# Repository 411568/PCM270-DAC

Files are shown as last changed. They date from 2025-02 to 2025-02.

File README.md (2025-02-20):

<p align="center">
PCM270-DAC
</p>

<h2>🧐 Features</h2>

USB DAC based on the PCM270xC iC. Powered by a USB type C connector. Output is compliant with the Line Out specification.
The included gerber files and BOM are made for JLCPCB. All of the components are taken from the LCSC library, meaning you can have the board assembled by JLC.
Important note: the board has not been tested yet.

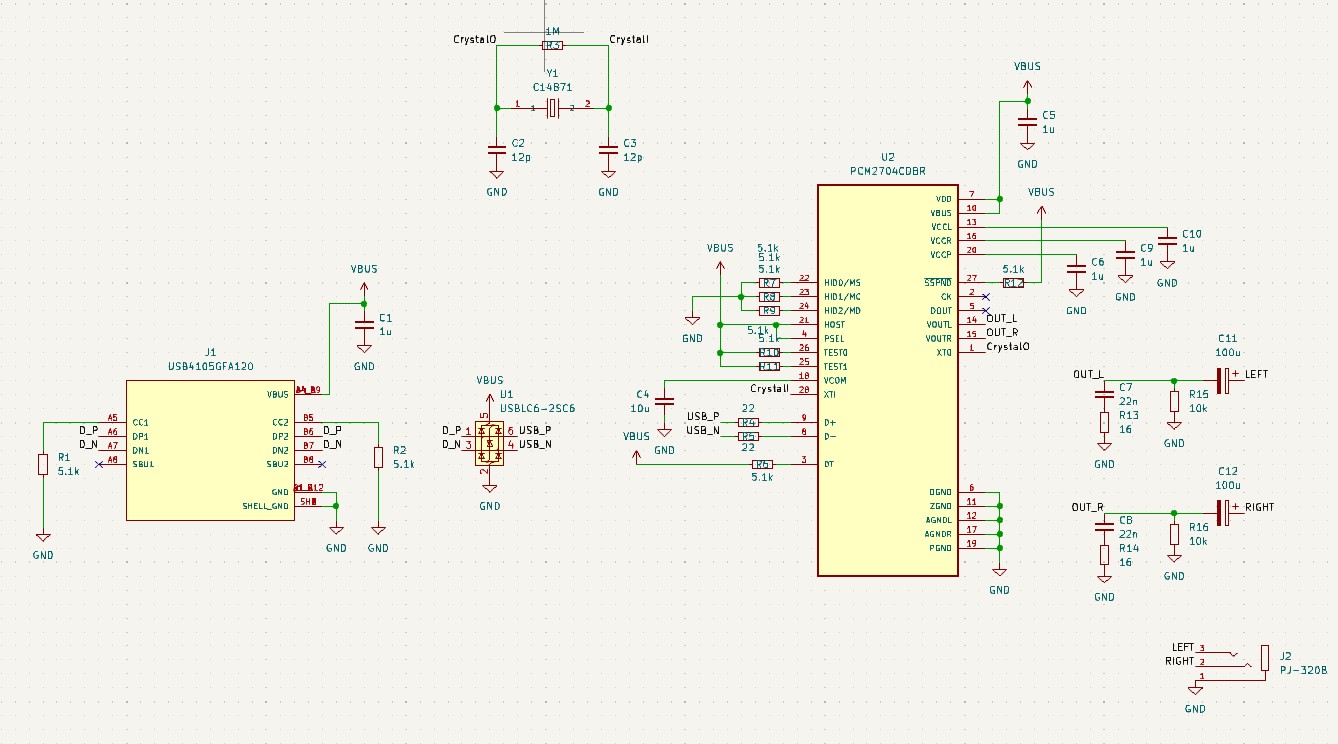
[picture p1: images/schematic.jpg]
schematic


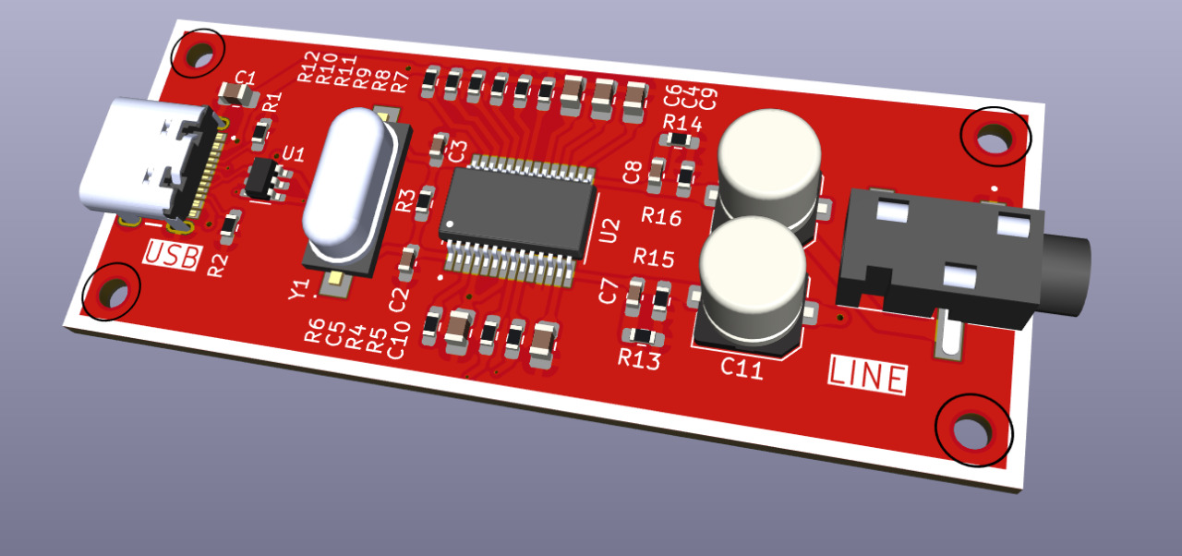
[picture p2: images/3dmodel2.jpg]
PCB 3d model


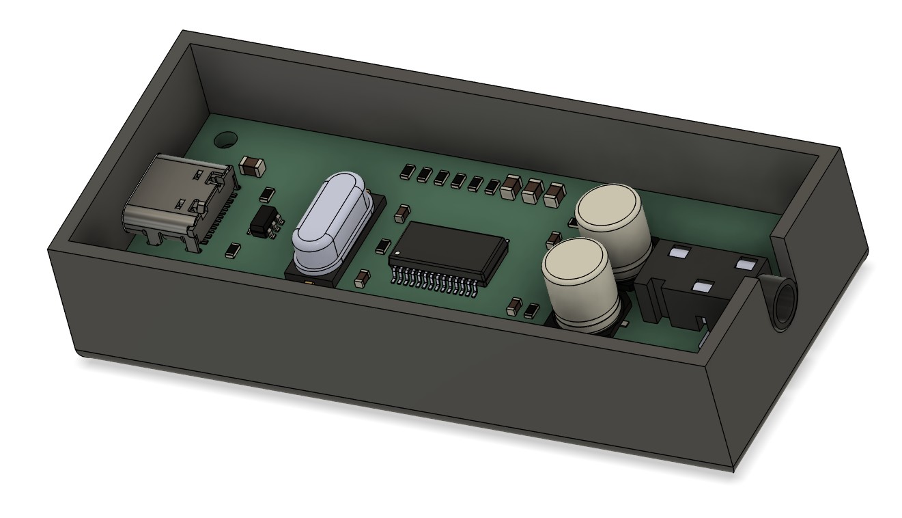
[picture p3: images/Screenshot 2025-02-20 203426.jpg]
enclosure


<h2>🛡️ License:</h2>

This project is licensed under the MIT License.

<h2> 🙋‍♂️Authors </h2>

- Krzysztof Sikora

<h2>💖Like my work?</h2>

If you have any questions about the project feel free to contact us via email: krzysieksikora717@gmail.com

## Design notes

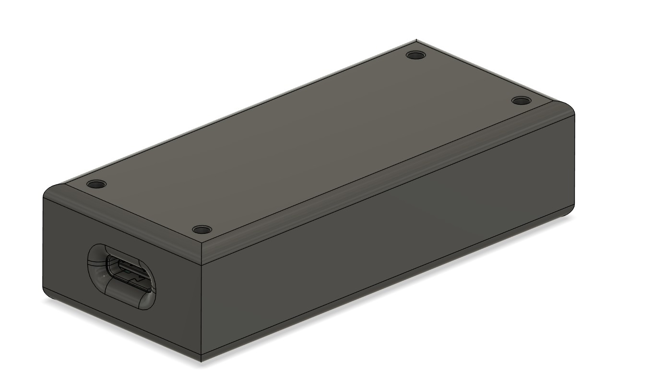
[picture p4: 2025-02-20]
images/Screenshot 2025-02-20 203409.jpg

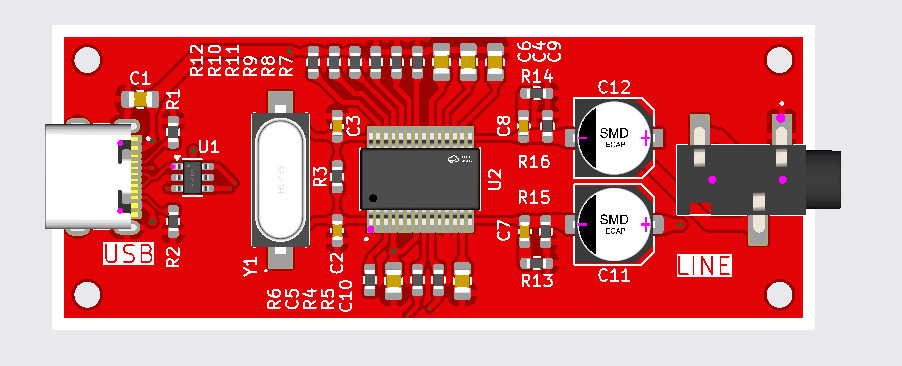
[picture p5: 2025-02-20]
images/3dmodel.jpg

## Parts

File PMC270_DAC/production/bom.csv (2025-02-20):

Designator | Footprint | Quantity | Value | LCSC Part #
C1, C10, C5, C6, C9 | 0805 | 5 | 1u | C28323
C11, C12 | C_Elec_6.3x7.7 | 2 | 100u | C3338
C2, C3 | 0603 | 2 | 12p | C38523
C4 | 0805 | 1 | 10u | C15850
C7, C8 | 0603 | 2 | 22n | C21122
LINE | BOOMELE_PJ-320B | 1 | PJ-320B | C18594
R1, R10, R11, R12, R2, R6, R7, R8, R9 | 0603 | 9 | 5.1k | C23186
R13, R14 | 0603 | 2 | 16 | C23345
R15, R16 | 0603 | 2 | 10k | C15401
R3 | 0603 | 1 | 1M | C22935
R4, R5 | 0603 | 2 | 22 | C23345
U1 | SOT-23-6 | 1 | USBLC6-2SC6 | C7519
U2 | SOP65P780X200-28N | 1 | PCM2704CDBR | C2859784
USB | GCT_USB4105GFA120 | 1 | USB4105GFA120 | C136423
Y1 | XTAL1170X500X450 | 1 | C14871 | C14871

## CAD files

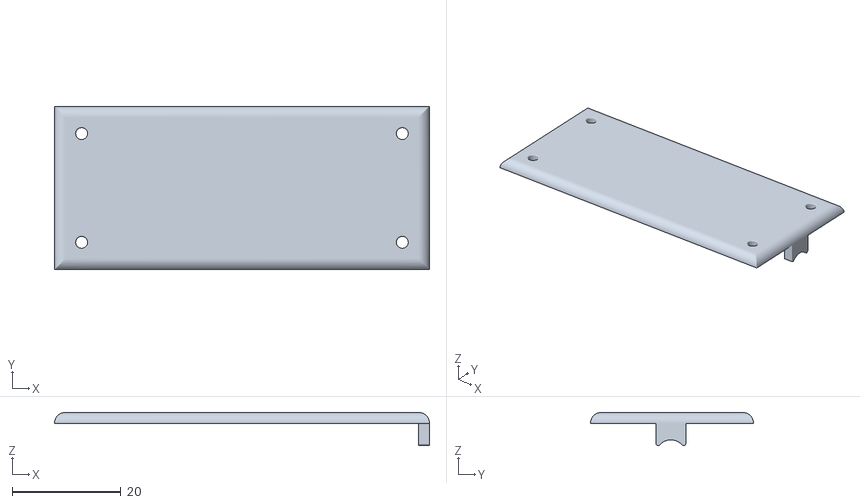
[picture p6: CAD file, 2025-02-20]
3D models/PMC270_DAC top.stl
69.0 x 30.0 x 6.10

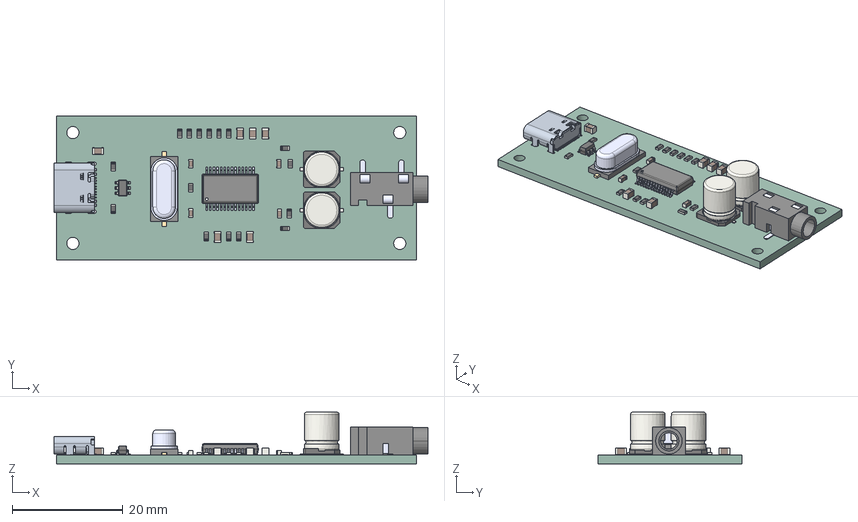
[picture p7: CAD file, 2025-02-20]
PMC270_DAC/PMC270_DAC.step
67.5 x 26.0 x 9.35 mm
R_0603_1608Metric x 16
C_0805_2012Metric x 6
C_Elec_63x77 x 2
C_0603_1608Metric x 4
SN65C3243DBR
SOT_23_6
FOXSDLF_160-20
PJ-320B
USB4105GFA120
PMC270_DAC_PCB

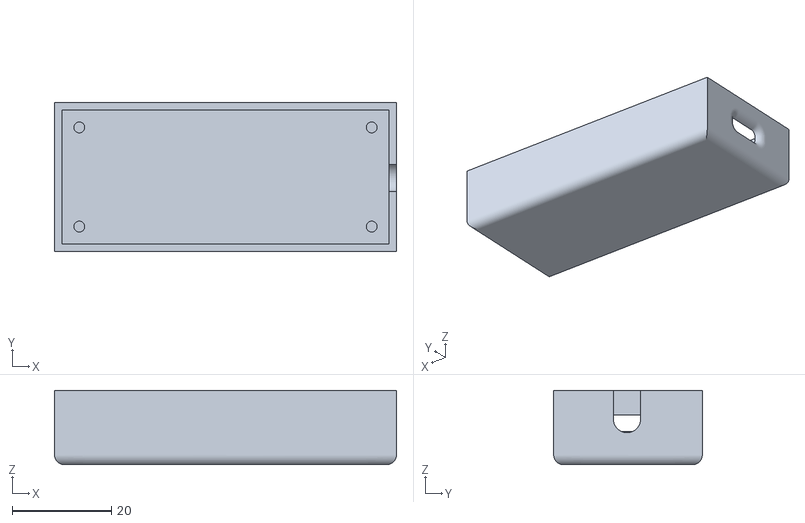
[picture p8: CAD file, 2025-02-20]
3D models/PMC270_DAC bottom.stl
69.0 x 30.0 x 15.0

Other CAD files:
3D models/PMC270_DAC v2.f3d

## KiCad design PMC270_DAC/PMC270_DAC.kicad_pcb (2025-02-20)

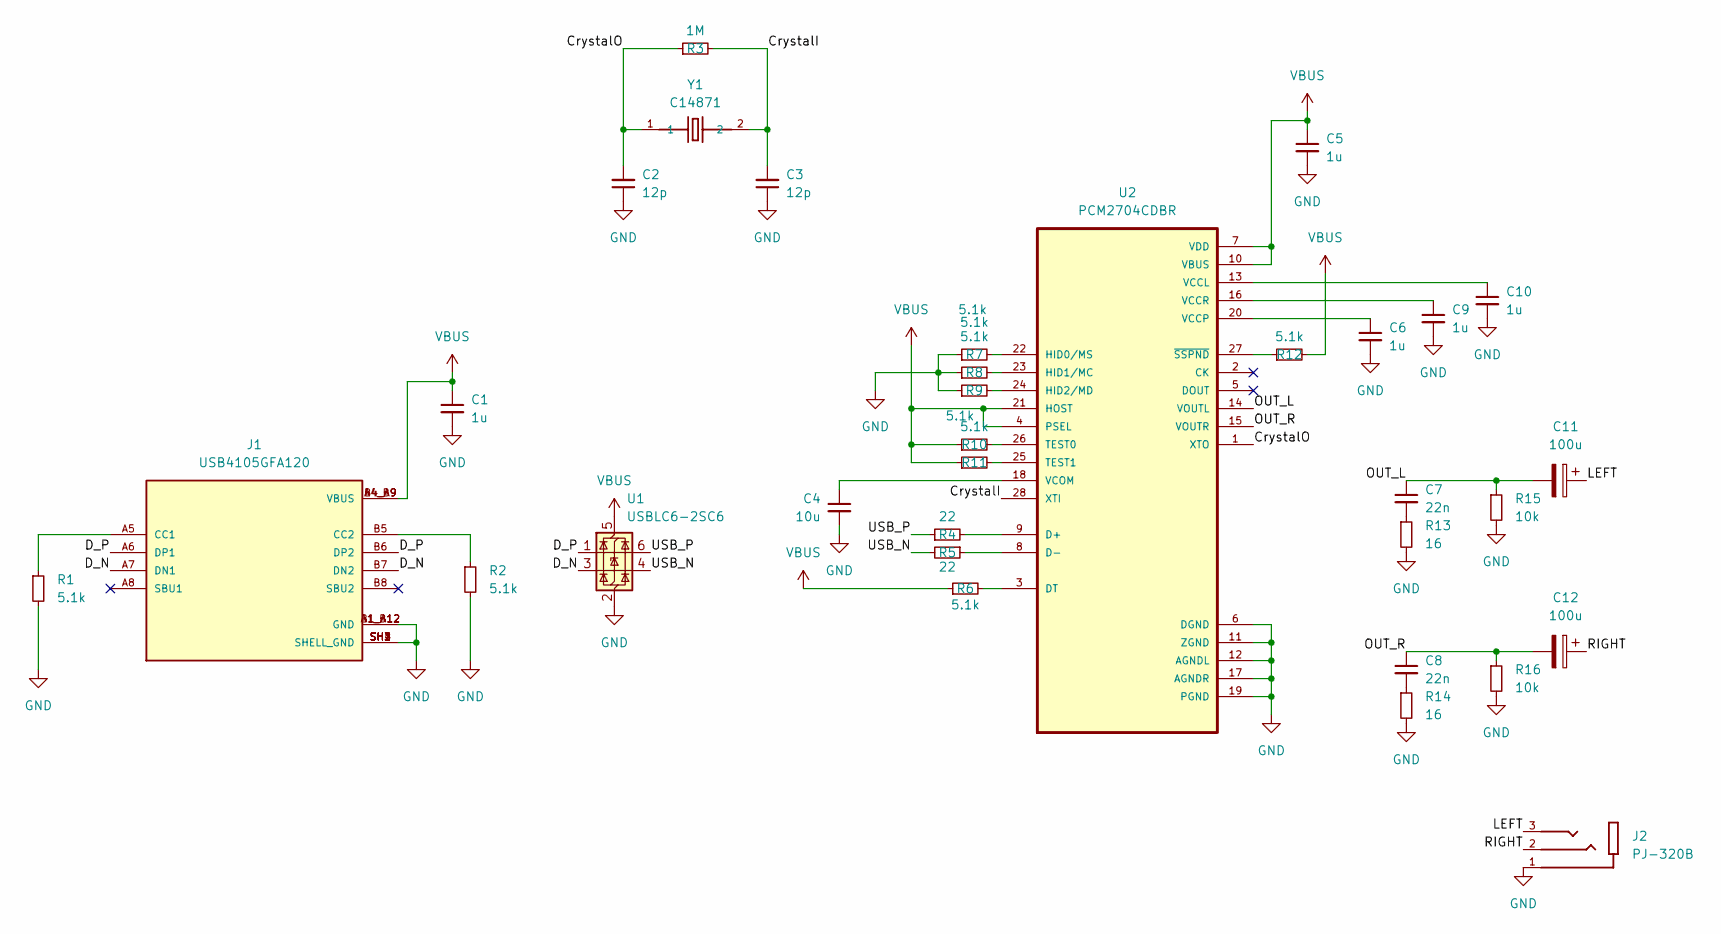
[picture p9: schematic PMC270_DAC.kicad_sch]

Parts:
C1, C5, C6, C9, C10: 1u; C_0805_2012Metric_Pad1.18x1.45mm_HandSolder
C2, C3: 12p; C_0603_1608Metric_Pad1.08x0.95mm_HandSolder
C4: 10u; C_0805_2012Metric_Pad1.18x1.45mm_HandSolder
C7, C8: 22n; C_0603_1608Metric_Pad1.08x0.95mm_HandSolder
C11, C12: 100u; C_Elec_6.3x7.7
J1: USB4105GFA120; GCT_USB4105GFA120; PARTREV B3
J2: PJ-320B; BOOMELE_PJ-320B
R1, R2, R6, R7, R8, R9, R10, R11, R12: 5.1k; R_0603_1608Metric_Pad0.98x0.95mm_HandSolder
R3: 1M; R_0603_1608Metric_Pad0.98x0.95mm_HandSolder
R4, R5: 22; R_0603_1608Metric_Pad0.98x0.95mm_HandSolder
R13, R14: 16; R_0603_1608Metric_Pad0.98x0.95mm_HandSolder
R15, R16: 10k; R_0603_1608Metric_Pad0.98x0.95mm_HandSolder
U1: USBLC6-2SC6; SOT-23-6
U2: PCM2704CDBR; SOP65P780X200-28N
Y1: C14871; XTAL1170X500X450

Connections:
/CrystalI: C3.2, R3.2, U2.28 (XTI), Y1.2
/CrystalO: C2.2, R3.1, U2.1 (XTO), Y1.1
/D_N: J1.A7 (DN1), J1.B7 (DN2), U1.3 (I/O2); also elsewhere on the board
/D_P: J1.A6 (DP1), J1.B6 (DP2), U1.1 (I/O1); also elsewhere on the board
/LEFT: C11.1, J2.3; also elsewhere on the board
/OUT_L: C7.1, C11.2, R15.1, U2.14 (VOUTL)
/OUT_R: C8.1, C12.2, R16.1, U2.15 (VOUTR)
/RIGHT: C12.1, J2.2; also elsewhere on the board
/USB_N: R5.2, U1.4 (I/O2)
/USB_P: R4.1, U1.6 (I/O1)
GND: C1.2, C2.1, C3.1, C4.2, C5.2, C6.2, C9.2, C10.2, J1.A1_B12 (GND), J1.B1_A12 (GND), J1.SH1 (SHELL_GND), J1.SH2 (SHELL_GND), J1.SH3 (SHELL_GND), J1.SH4 (SHELL_GND), J2.1, R1.2, R2.2, R7.1, R8.1, R9.1, R13.2, R14.2, R15.2, R16.2, U1.2 (GND), U2.6 (DGND), U2.11 (ZGND), U2.12 (AGNDL), U2.17 (AGNDR), U2.19 (PGND); also elsewhere on the board
unnamed: C7.2, R13.1
unnamed: C8.2, R14.1
unnamed 13: J1.A5 (CC1), R1.1; also elsewhere on the board
unnamed 14: J1.B5 (CC2), R2.1; also elsewhere on the board
unnamed: R4.2, U2.9 (D+)
unnamed: R5.1, U2.8 (D-)
unnamed: R6.2, U2.3 (DT)
unnamed: R7.2, U2.22 (HID0/MS)
unnamed: R8.2, U2.23 (HID1/MC)
unnamed: R9.2, U2.24 (HID2/MD)
unnamed: R10.2, U2.26 (TEST0)
unnamed: R11.2, U2.25 (TEST1)
unnamed: C10.1, U2.13 (VCCL)
unnamed: C6.1, U2.20 (VCCP)
unnamed: C9.1, U2.16 (VCCR)
unnamed: C4.1, U2.18 (VCOM)
unnamed: R12.1, U2.27 (~SSPND)
VBUS: C1.1, C5.1, J1.A4_B9 (VBUS), J1.B4_A9 (VBUS), R6.1, R10.1, R11.1, R12.2, U1.5 (VBUS), U2.4 (PSEL), U2.7 (VDD), U2.10 (VBUS), U2.21 (HOST); also elsewhere on the board

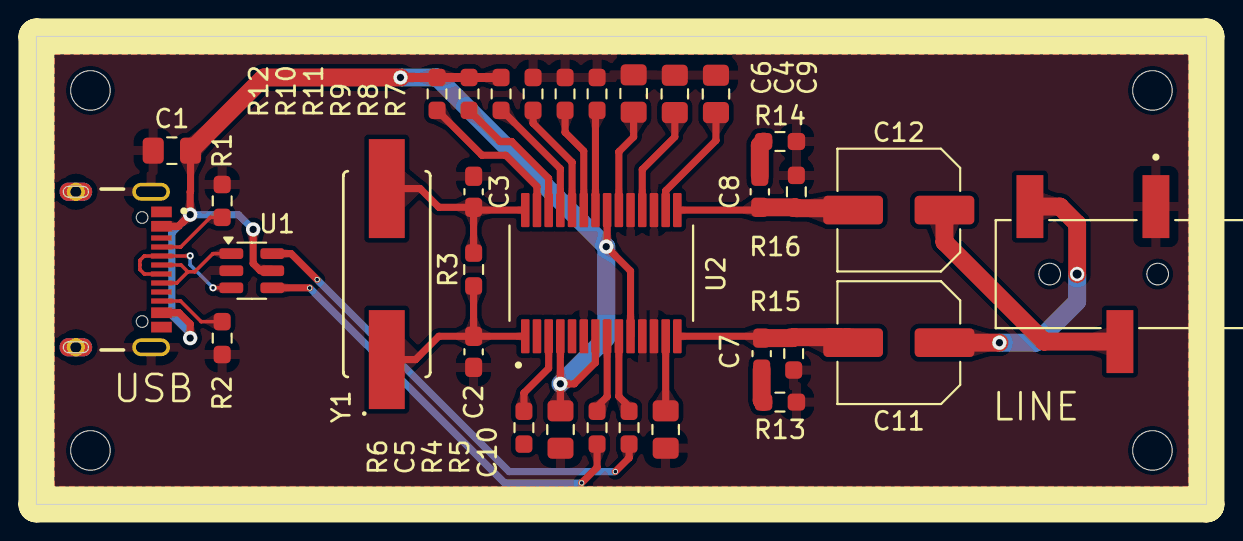
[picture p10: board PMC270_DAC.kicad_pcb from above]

Board: 2 copper layers, 65.0 x 26.0 mm, 33 parts (0 on the bottom side), 29 nets.

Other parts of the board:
LINE: PJ-320B; BOOMELE_PJ-320B
USB: USB4105GFA120; GCT_USB4105GFA120

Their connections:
/D_N: USB.A7 (DN1), USB.B7 (DN2); also elsewhere on the board
/D_P: USB.A6 (DP1), USB.B6 (DP2); also elsewhere on the board
/LEFT: LINE.3; also elsewhere on the board
/RIGHT: LINE.2; also elsewhere on the board
GND: LINE.1, USB.A1_B12 (GND), USB.B1_A12 (GND), USB.SH1 (SHELL_GND), USB.SH2 (SHELL_GND), USB.SH3 (SHELL_GND), USB.SH4 (SHELL_GND); also elsewhere on the board
unnamed 13: USB.A5 (CC1); also elsewhere on the board
unnamed 14: USB.B5 (CC2); also elsewhere on the board
VBUS: USB.A4_B9 (VBUS), USB.B4_A9 (VBUS); also elsewhere on the board

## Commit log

2025-02-20 Added production files
    [bom.csv]
2025-02-20 added enclosure model
    [PMC270_DAC bottom.stl, PMC270_DAC top.stl, PMC270_DAC v2.f3d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]
